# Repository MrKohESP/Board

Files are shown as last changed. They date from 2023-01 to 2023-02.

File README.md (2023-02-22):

# Mr. Koh Board
Mr. Koh ESP32-C3 RISC-V Development Board
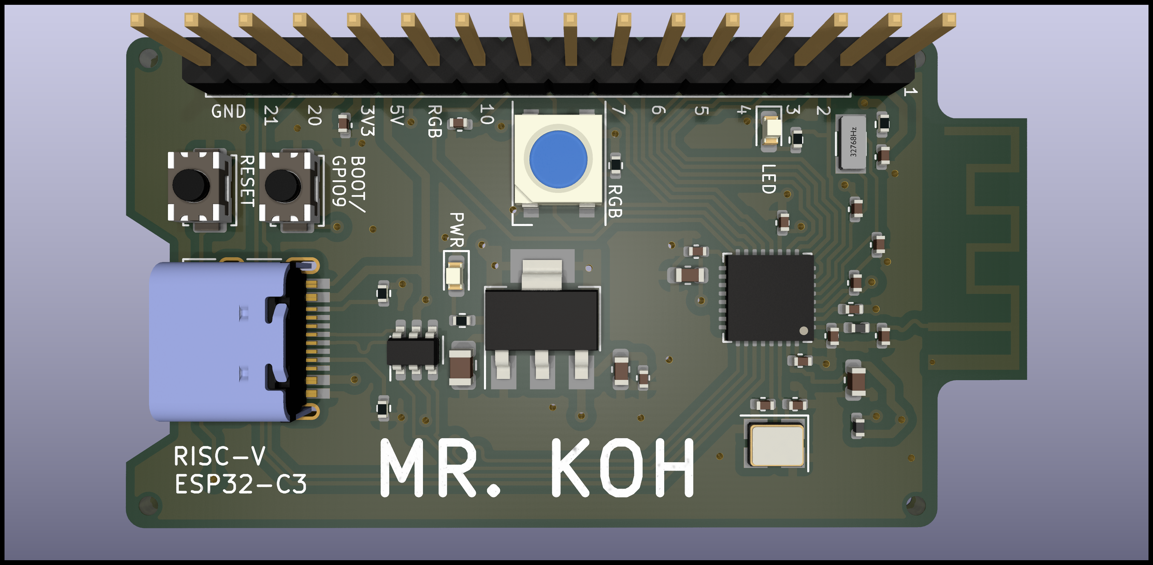
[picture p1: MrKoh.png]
MrKoh


## The Mr. Koh is a birthday project for Mr. Koh.
# Happy Birthday Mr. Koh! 🥳
Mr. Koh is an Open Hardware, Open Source (GPL3.0), ESP32-C3 RISC-V Developement Board.

## Features
* [RISC-V](https://github.com/jameslzhu/riscv-card/blob/586b60b5c351b3e6e6ebbf7130b9f93013b2e511/riscv-card.pdf) instruction set
* [Espressif Systems ESP32-C3FH4 MCU](https://www.espressif.com/en/products/socs/esp32-c3)
* 400K SDRAM and 4MB Flash memory
* Real-Time Clock support
* 10 GPIOs with RESET, BOOT, and RGB OUT
* [RGB](http://www.world-semi.com/Certifications/details-111-4.html), power and data leds
* Built-in USB Type C flashing and [JTAG debugging](https://docs.espressif.com/projects/esp-idf/en/latest/esp32c3/api-guides/usb-serial-jtag-console.html)
* ESD protected
* [FreeRTOS](https://www.freertos.org/Using-FreeRTOS-on-RISC-V.html) Supported when using [ESP-IDF](https://docs.espressif.com/projects/esp-idf/en/v5.0/esp32/)

## Pinout
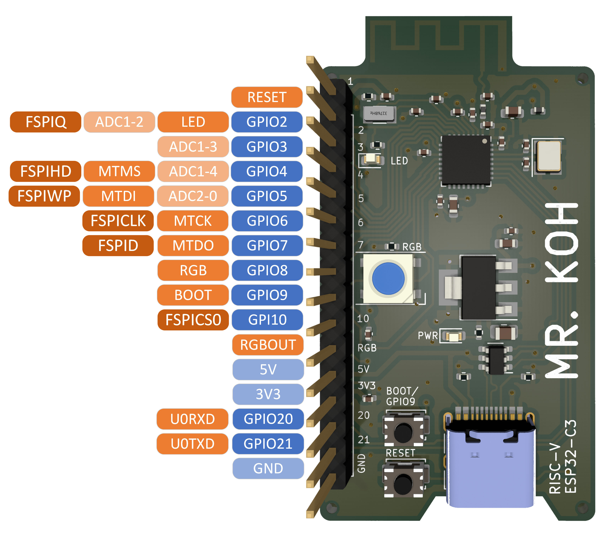
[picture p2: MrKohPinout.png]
MrKoh


## Files
* [Datasheet](https://www.espressif.com/sites/default/files/documentation/esp32-c3_datasheet_en.pdf)
* [Schematic](Schematic.pdf) 
* [BOM](Hardware/Fab/MrKohBOM.csv)
* [CPL (Position)](Hardware/Fab/MrKoh-top-pos.csv)
* [PCB Front](MrKoh.png)
* [PCB Back](MrKohBack.png)

## History
1. v1 Designed 01/23/2023.
2. v1 Sent to production 01/26/2023.
3. v1 Shipped 01/30/2023.
4. v1 Arrival 02/03/2023.
5. v1 Issues with USB Type C connector clearance and USB Type C pinout resulting in connectivity problems.
6. v1 LED was on all the time.
7. Rev 2 Carved out a space for the Type C connector and redid the PCB for correct pinout.
8. Rev 2 Removed Q1 and pull up, Pin GPIO2 is now just an LED.  Reworked PCB to remove Q1 and R7. 
9. Rev 2 Reworked the Pin Header pins to allow 5V from USB and to use that pin in place of USB.
10. Rev 2 Sent to production 02/06/2023, Shenzhen, Guangdong, China Time (UTC+8).
11. Rev 2 pcb finished 02/07/2023
12. Rev 2 assembly finished 2023-02-08 06:37:05 (local time).
13. Rev 2 waiting for Carrier to pick up completed boards.
14. Rev 2 delivered on Mon Feb 13 at 16:43
15. Rev 2 Tests indicate board is fully functional.

## Photo
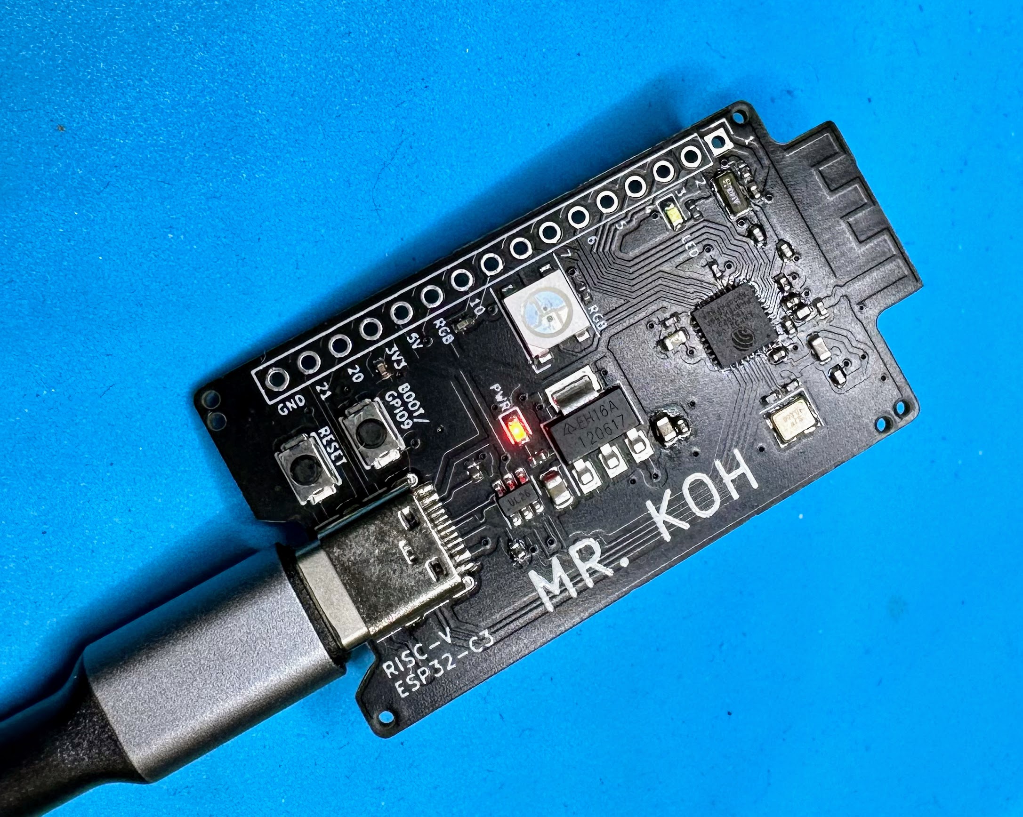
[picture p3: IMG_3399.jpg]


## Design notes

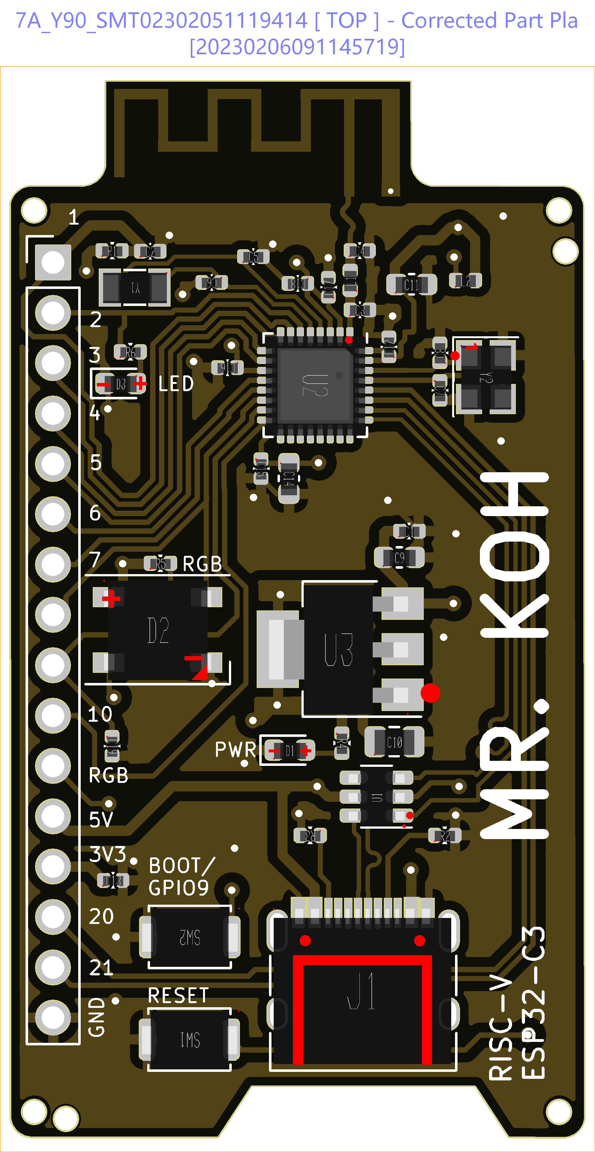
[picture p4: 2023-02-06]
Hardware/Fab/Proofs/Produce_DanZhi.SMT_Snapshot.Top.2452577A_Y90.SMT02302051119414.png

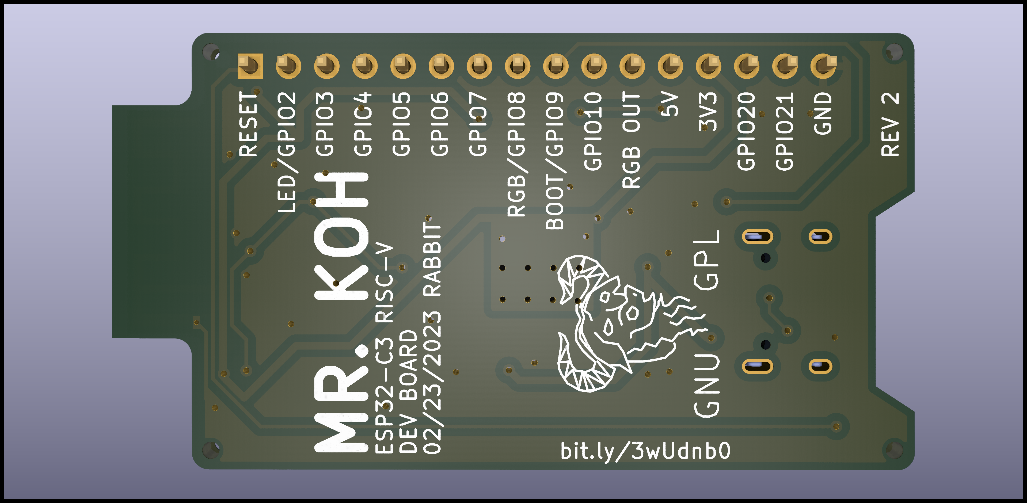
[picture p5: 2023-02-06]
MrKohBack.png

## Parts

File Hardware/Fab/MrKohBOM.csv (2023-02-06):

Comment | Designator | Footprint | LCSC
100n | C1,C2,C12,C13,C15,C16,C17,C18,C19 | Capacitor_SMD:C_0402_1005Metric | C60474
22u | C10 | Capacitor_SMD:C_0805_2012Metric | C45783
3p3 | C3,C4 | Capacitor_SMD:C_0402_1005Metric | C1565
22p | C5,C6,C7,C8 | Capacitor_SMD:C_0402_1005Metric | C1555
10u | C9,C11,C14 | Capacitor_SMD:C_0603_1608Metric | C96446
USB_C_Receptacle_USB2.0 | J1 | Connector_USB:USB_C_Receptacle_HRO_TYPE-C-31-M-12 | C165948
2n2 | L1,L2 | Inductor_SMD:L_0402_1005Metric | C76790
MMBT3904 | Q1 | Package_TO_SOT_SMD:SOT-23 | C20526
5K1 | R1,R2,R3,R5 | Resistor_SMD:R_0402_1005Metric | C25905
1K5 | R4,R6 | Resistor_SMD:R_0402_1005Metric | C25867
RESET | SW1 | Button_Switch_SMD:SW_Push_SPST_NO_Alps_SKRK | C202388
BOOT | SW2 | Button_Switch_SMD:SW_Push_SPST_NO_Alps_SKRK | C202388
USBLC6-2SC6 | U1 | Package_TO_SOT_SMD:SOT-23-6 | C7519
ESP32-C3-FH4 | U2 | Package_DFN_QFN:QFN-32-1EP_5x5mm_P0.5mm_EP3.45x3.45mm | C2858491
AZ1117-3.3 | U3 | Package_TO_SOT_SMD:SOT-223-3_TabPin2 | C92517
32K (C32346) | Y1 | Crystal:Crystal_SMD_3215-2Pin_3.2x1.5mm | C32346
40Mhz (C252256) | Y2 | Crystal:Crystal_SMD_3225-4Pin_3.2x2.5mm | C252256
WHT | D1 | LED_SMD:LED_0603_1608Metric | C2286
RED | D3 | LED_SMD:LED_0603_1608Metric | C2290
WS2812B | D2 | LED_SMD:LED_WS2812B_PLCC4_5.0x5.0mm_P3.2mm | C2843785

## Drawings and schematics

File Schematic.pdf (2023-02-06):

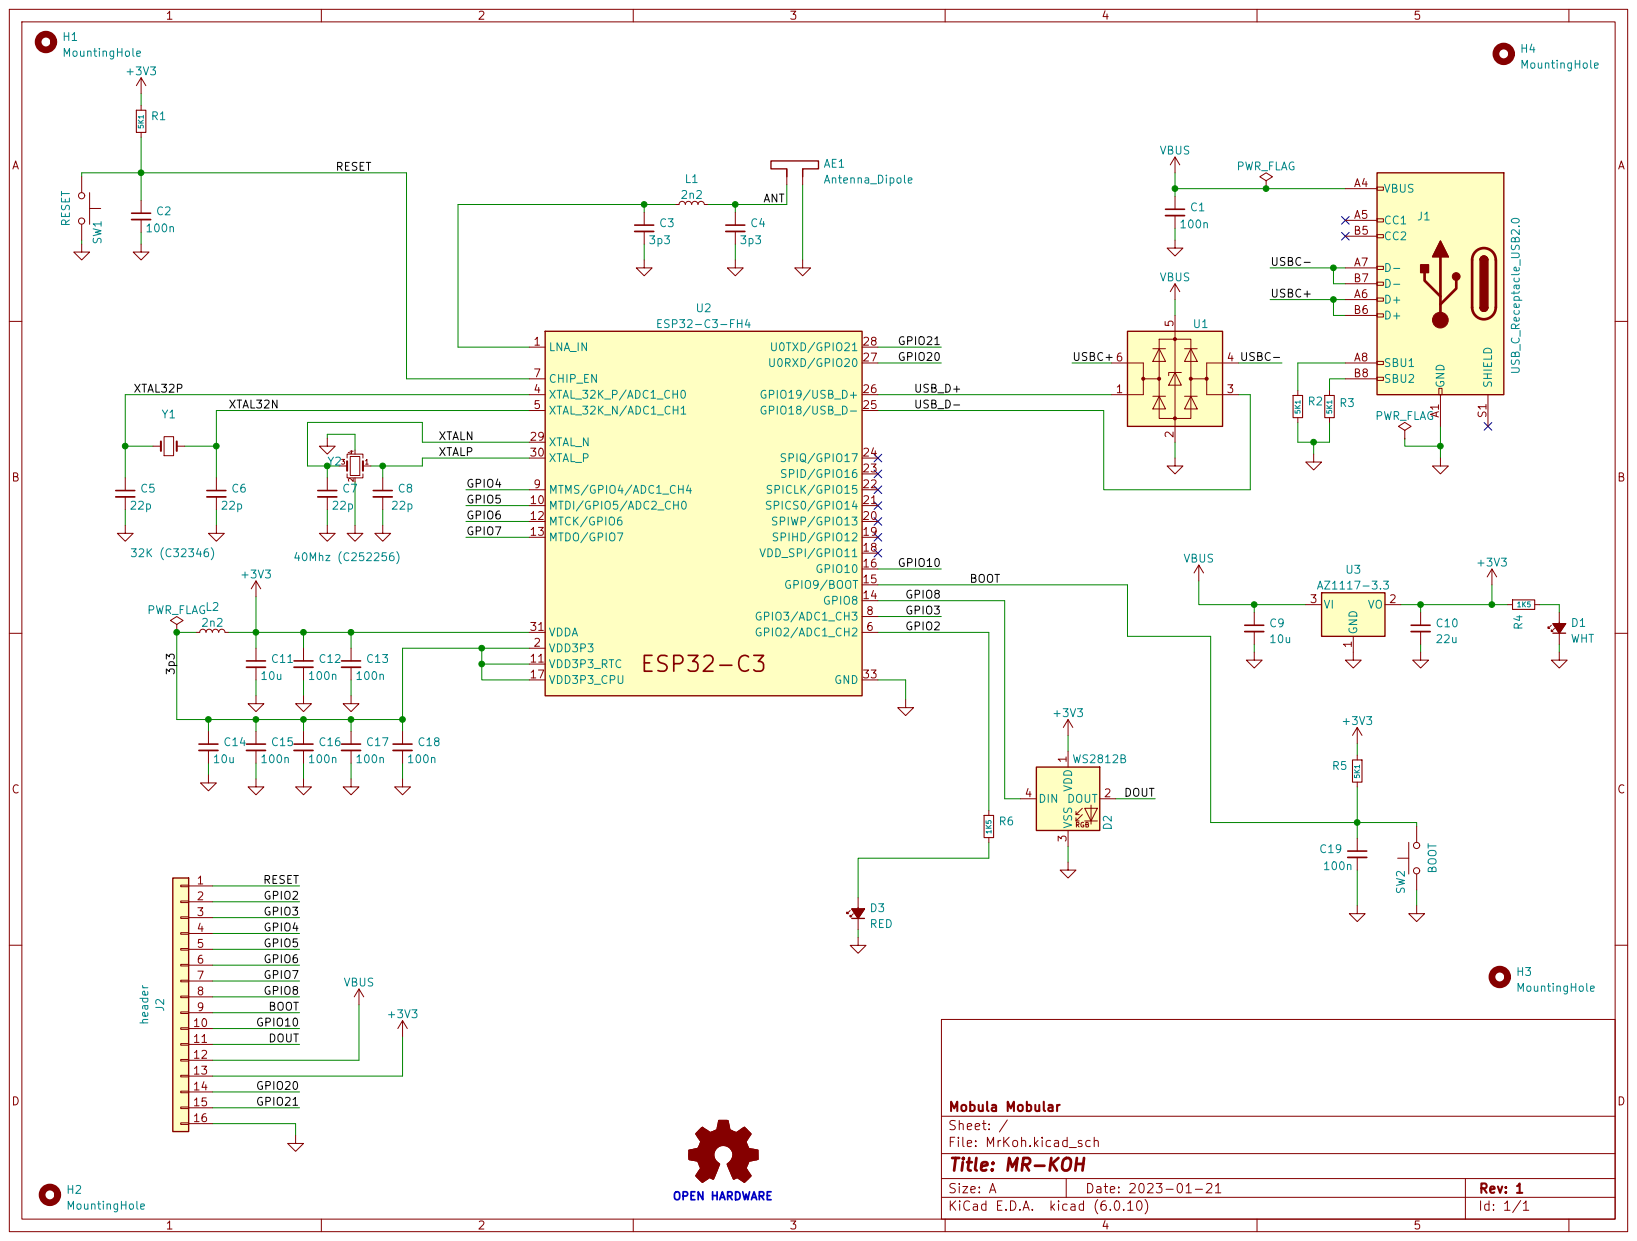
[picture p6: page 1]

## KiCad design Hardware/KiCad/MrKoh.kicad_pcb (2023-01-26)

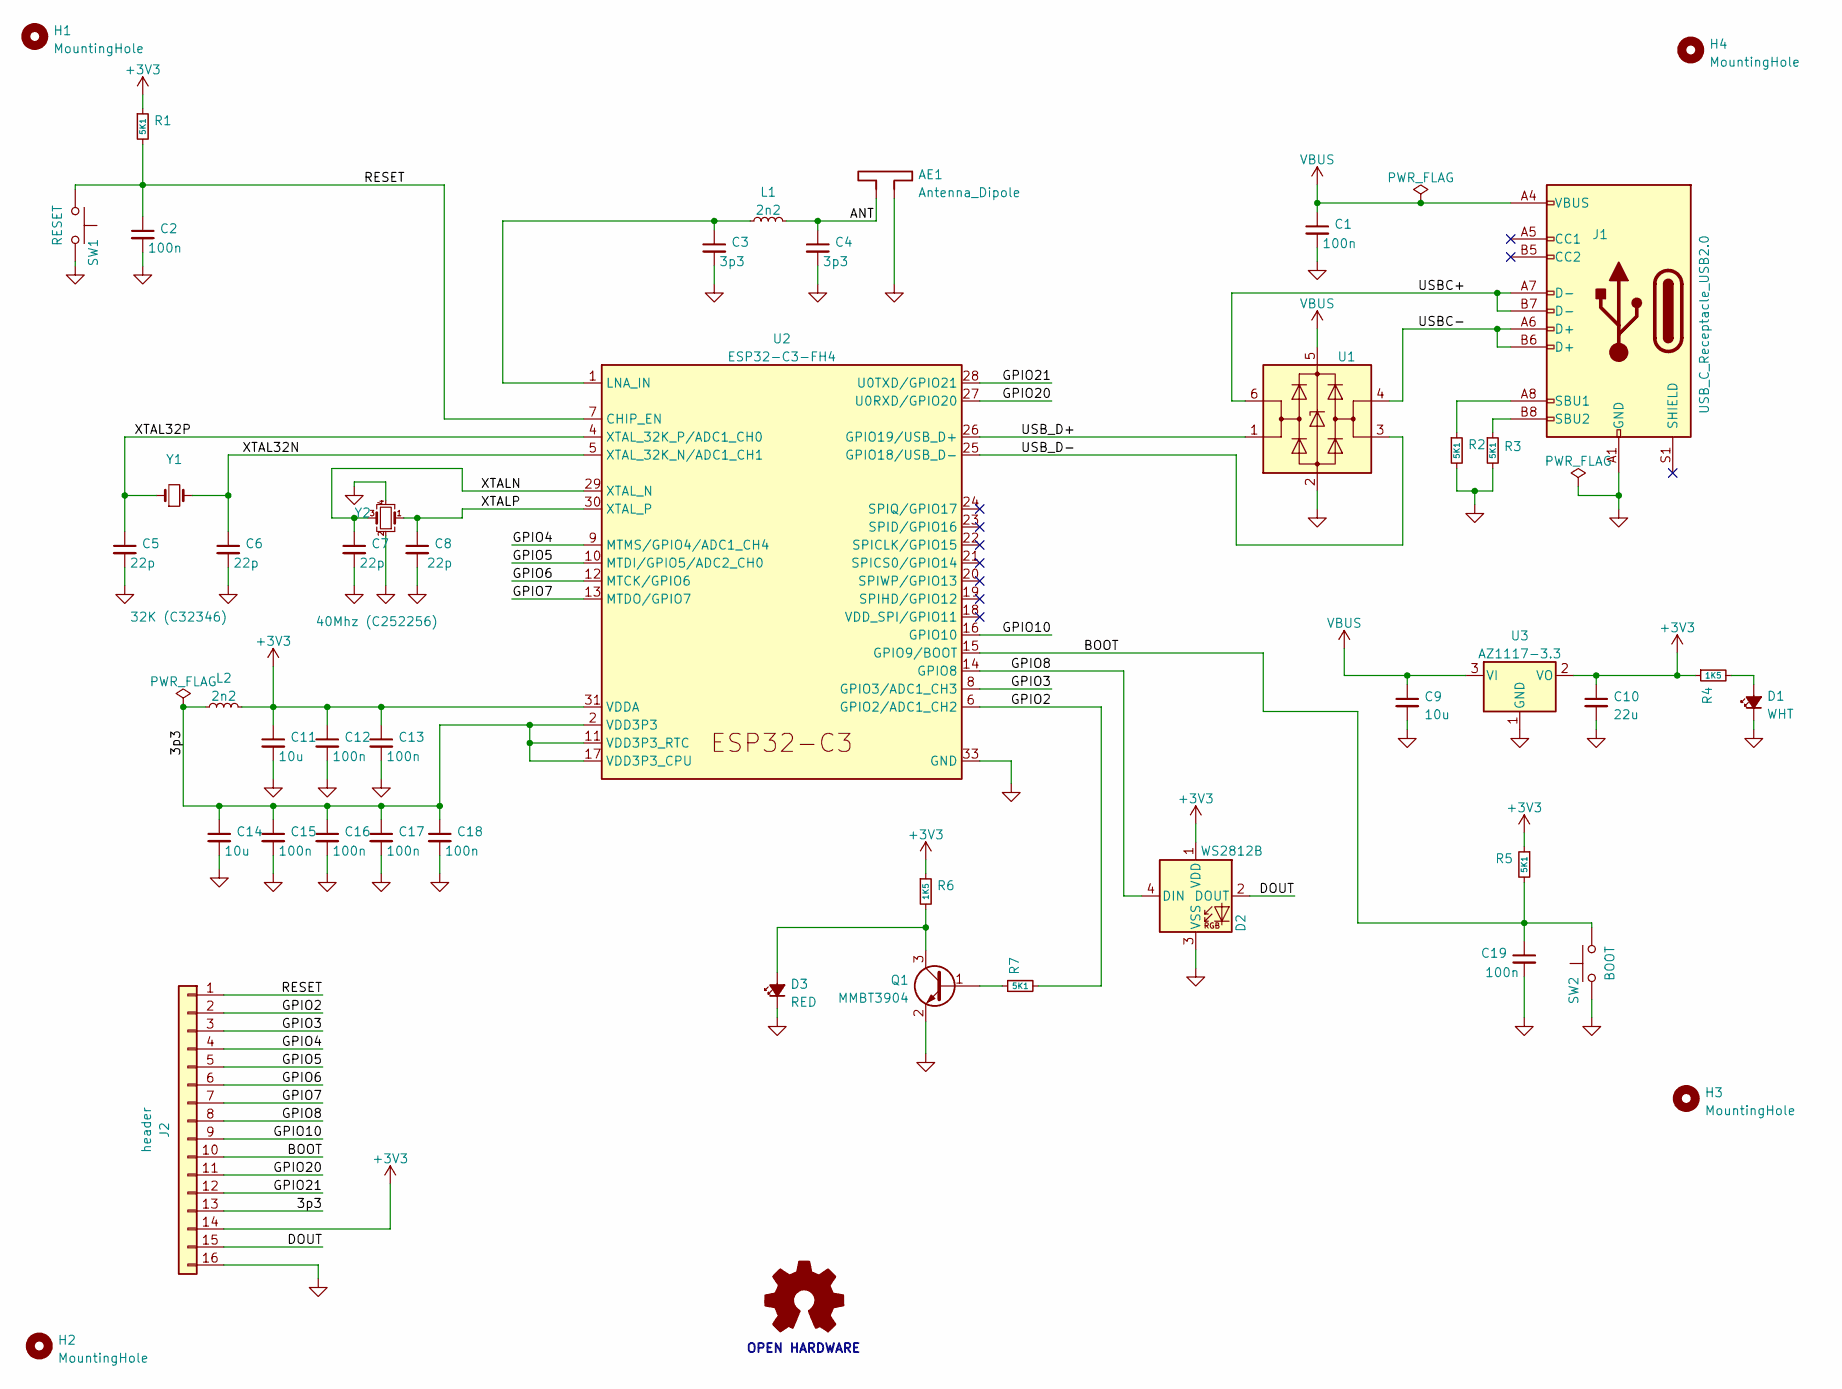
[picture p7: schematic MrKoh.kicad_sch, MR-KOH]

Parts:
AE1: Antenna_Dipole; Texas_SWRA117D_2.4GHz_Left
C1, C2, C12, C13, C15, C16, C17, C18, C19: 100n; C_0402_1005Metric; LCSC C60474
C3, C4: 3p3; C_0402_1005Metric; LCSC C1565
C5, C6, C7, C8: 22p; C_0402_1005Metric; LCSC C1555
C9, C11, C14: 10u; C_0603_1608Metric; LCSC C96446
C10: 22u; C_0805_2012Metric; LCSC C45783
D1: WHT; LED_0603_1608Metric; LCSC C2286
D2: WS2812B; LED_WS2812B_PLCC4_5.0x5.0mm_P3.2mm
D3: RED; LED_0603_1608Metric; LCSC C2290
H1, H2, H3, H4: MountingHole; MountingHole_1152_JLCPCB
J1: USB_C_Receptacle_USB2.0; USB_C_Receptacle_HRO_TYPE-C-31-M-12; LCSC C165948
J2: header; PinHeader_1x16_P2.54mm_Vertical
L1, L2: 2n2; L_0402_1005Metric; LCSC C76790
LOGO1: Logo_Open_Hardware_Small; Symbol_GNU-Logo_SilkscreenTop
Q1: MMBT3904; SOT-23; LCSC C20526
R1, R2, R3, R5, R7: 5K1; R_0402_1005Metric; LCSC C25905
R4, R6: 1K5; R_0402_1005Metric; LCSC C25867
SW1: RESET; SW_Push_SPST_NO_Alps_SKRK; LCSC C202388
SW2: BOOT; SW_Push_SPST_NO_Alps_SKRK; LCSC C202388
U1: USBLC6-2SC6; SOT-23-6; LCSC C7519
U2: ESP32-C3-FH4; QFN-32-1EP_5x5mm_P0.5mm_EP3.45x3.45mm; LCSC C2858491
U3: AZ1117-3.3; SOT-223-3_TabPin2; LCSC C92517
Y1: 32K (C32346); Crystal_SMD_3215-2Pin_3.2x1.5mm; LCSC C32346
Y2: 40Mhz (C252256); Crystal_SMD_3225-4Pin_3.2x2.5mm; LCSC C252256

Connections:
+3V3: C10.1, C11.1, C12.1, C13.1, D2.1 (VDD), J2.14, L2.2, R1.1, R4.1, R5.1, R6.1, U2.31 (VDDA), U2.32 (VDDA), U3.2 (VO)
/3p3: C14.1, C15.1, C16.1, C17.1, C18.1, J2.13, L2.1, U2.2 (VDD3P3), U2.3 (VDD3P3), U2.11 (VDD3P3_RTC), U2.17 (VDD3P3_CPU)
/ANT: AE1.1, C4.1, L1.2
/BOOT: C19.1, J2.10, R5.2, SW2.1, U2.15 (GPIO9/BOOT)
/DOUT: D2.2 (DOUT), J2.15
/GPIO2: J2.2, R7.2, U2.6 (GPIO2/ADC1_CH2)
/GPIO3: J2.3, U2.8 (GPIO3/ADC1_CH3)
/GPIO4: J2.4, U2.9 (MTMS/GPIO4/ADC1_CH4)
/GPIO5: J2.5, U2.10 (MTDI/GPIO5/ADC2_CH0)
/GPIO6: J2.6, U2.12 (MTCK/GPIO6)
/GPIO7: J2.7, U2.13 (MTDO/GPIO7)
/GPIO8: D2.4 (DIN), J2.8, U2.14 (GPIO8)
/GPIO10: J2.9, U2.16 (GPIO10)
/GPIO20: J2.11, U2.27 (U0RXD/GPIO20)
/GPIO21: J2.12, U2.28 (U0TXD/GPIO21)
/RESET: C2.1, J2.1, R1.2, SW1.1, U2.7 (CHIP_EN)
/USBC+: J1.A7 (D-), J1.B7 (D-), U1.6 (I/O1)
/USBC-: J1.A6 (D+), J1.B6 (D+), U1.4 (I/O2)
/USB_D+: U1.1 (I/O1), U2.26 (GPIO19/USB_D+)
/USB_D-: U1.3 (I/O2), U2.25 (GPIO18/USB_D-)
/XTAL32N: C6.1, U2.5 (XTAL_32K_N/ADC1_CH1), Y1.2
/XTAL32P: C5.1, U2.4 (XTAL_32K_P/ADC1_CH0), Y1.1
/XTALN: C7.1, U2.29 (XTAL_N), Y2.3
/XTALP: C8.1, U2.30 (XTAL_P), Y2.1
GND: AE1.2, C1.2, C2.2, C3.2, C4.2, C5.2, C6.2, C7.2, C8.2, C9.2, C10.2, C11.2, C12.2, C13.2, C14.2, C15.2, C16.2, C17.2, C18.2, C19.2, D1.1 (K), D2.3 (VSS), D3.1 (K), J1.A1 (GND), J1.A12 (GND), J1.B1 (GND), J1.B12 (GND), J2.16, Q1.2 (E), R2.2, R3.2, SW1.2, SW2.2, U1.2 (GND), U2.33 (GND), U3.1 (GND), Y2.2, Y2.4
unnamed: C3.1, L1.1, U2.1 (LNA_IN)
unnamed: D1.2 (A), R4.2
unnamed: D3.2 (A), Q1.3 (C), R6.2
unnamed: J1.A8 (SBU1), R2.1
unnamed: J1.B8 (SBU2), R3.1
unnamed: Q1.1 (B), R7.1
VBUS: C1.1, C9.1, J1.A4 (VBUS), J1.A9 (VBUS), J1.B4 (VBUS), J1.B9 (VBUS), U1.5 (VBUS), U3.3 (VI)

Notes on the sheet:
OPEN HARDWARE

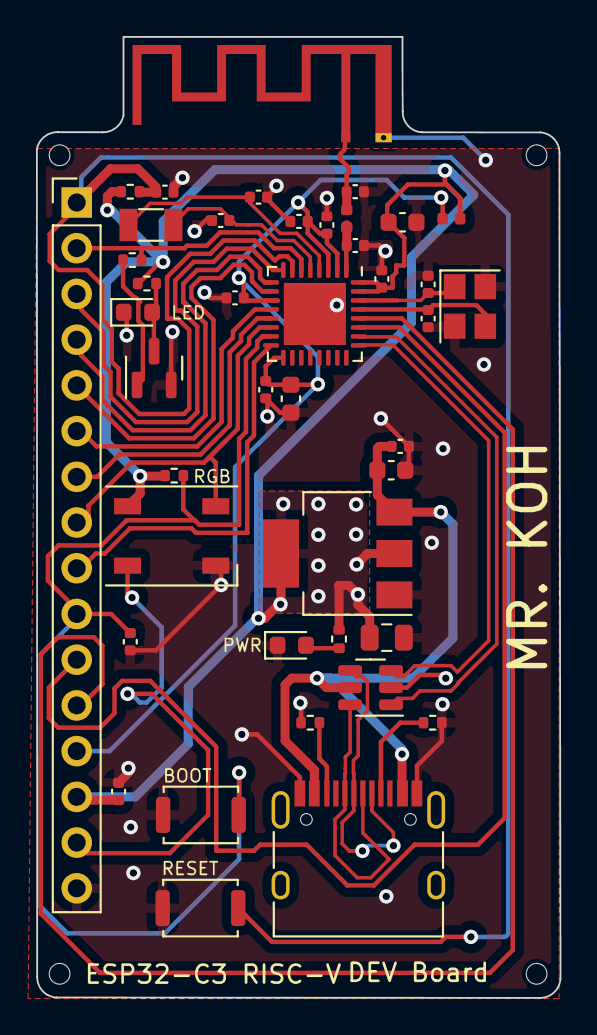
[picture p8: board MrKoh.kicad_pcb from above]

Board: 2 copper layers, 29.1 x 53.4 mm, 47 parts (1 on the bottom side), 32 nets.

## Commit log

2023-01-26 Add Board 3D Images
2023-01-26 Fabrication Files
    Fab Files from original order
    [MrKoh.kicad_pcb, MrKoh.kicad_sch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]
2023-01-26 Fabrication Files added
    Fab Files From Original Order
    [MrKoh.kicad_pcb, MrKoh.kicad_sch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]
2023-01-26 Part issue
    There was a problem with sourcing the original RGB part and changes to schematic, pcb, and fabrication files. Production proofs were added.
    [MrKoh.kicad_pcb, MrKoh.kicad_sch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]
2023-01-26 Production Zip
    Note changes to the csv files are not updated in the zip file but were uploaded after the fact in the bom and pos order proccess.
2023-01-27 Rename Hardware/Fabrication Files/espc4synth-B_Cu.gbl to Hardware/Fab/MrKoh.gbl
    [MrKoh.gbl]
2023-01-27 Rename Hardware/Fabrication Files/espc4synth-B_Mask.gbs to Hardware/Fab/MrKoh-B_Mask.gbs
    [MrKoh-B_Mask.gbs]
2023-01-27 Rename Hardware/Fabrication Files/espc4synth-B_Paste.gbp to Hardware/Fab/MrKoh-B_Paste.gbp
    [MrKoh-B_Paste.gbp]
2023-01-27 Rename Hardware/Fabrication Files/espc4synth-B_Silkscreen.gbo to Hardware/Fab/MrKoh-B_Silkscreen.gbo
    [MrKoh-B_Silkscreen.gbo]
2023-01-27 Rename Hardware/Fabrication Files/espc4synth-Edge_Cuts.gm1 to Hardware/Fab/MrKoh-Edge_Cuts.gm1
    [MrKoh-Edge_Cuts.gm1]
2023-01-27 Rename Hardware/Fabrication Files/espc4synth-F_Cu.gtl to Hardware/Fab/MrKoh-F_Cu.gtl
    [MrKoh-F_Cu.gtl]
2023-01-27 Rename Hardware/Fabrication Files/espc4synth-F_Mask.gts to Hardware/Fab/MrKoh-F_Mask.gts
    [MrKoh-F_Mask.gts]
2023-01-27 Rename Hardware/Fabrication Files/espc4synth-F_Paste.gtp to Hardware/Fab/MrKoh-F_Paste.gtp
    [MrKoh-F_Paste.gtp]
2023-01-27 Rename Hardware/Fabrication Files/espc4synth-F_Silkscreen.gto to Hardware/Fab/MrKoh-F_Silkscreen.gto
    [MrKoh-F_Silkscreen.gto]
2023-01-27 Rename Hardware/Fabrication Files/espc4synth-drl_map.gbr to Hardware/Fab/MrKoh-drl_map.gbr
    [MrKoh-drl_map.gbr]
2023-01-27 Rename Hardware/Fabrication Files/espc4synth-job.gbrjob to Hardware/Fab/MrKoh-job.gbrjob
    [MrKoh-job.gbrjob]
2023-01-27 Rename Hardware/Fabrication Files/espc4synth-top-pos.csv to Hardware/Fab/MrKoh-position.csv
    [MrKoh-position.csv]
2023-01-27 Rename Hardware/Fabrication Files/espc4synth.csv to Hardware/Fab/MrKoh_BOM.csv
    [MrKoh_BOM.csv]
2023-01-27 Rename Hardware/Fabrication Files/espc4synth.drl to Hardware/Fab/MrKoh.drl
    [MrKoh.drl]
2023-01-27 Rename Hardware/Kicad Files/MrKoh.kicad_pcb to Hardware/KiCad/MrKoh.kicad_pcb
    [MrKoh.kicad_pcb]
2023-01-27 Rename Hardware/Kicad Files/MrKoh.kicad_pro to Hardware/KiCad/MrKoh.kicad_pro
2023-01-27 Rename Hardware/Kicad Files/MrKoh.kicad_sch to Hardware/KiCad/MrKoh.kicad_sch
    [MrKoh.kicad_sch]
2023-02-06 v2 Fab Files
    [MrKoh-B_Cu.gbl, MrKoh-B_Mask.gbs, MrKoh-B_Paste.gbp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]
2023-02-22 photo physical board
